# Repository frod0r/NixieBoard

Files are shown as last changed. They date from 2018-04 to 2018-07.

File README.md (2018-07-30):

Here I try to recreate the schematics and layout of the nixie clock from this nice instrucables creator:
http://www.instructables.com/id/simple-user-adjustable-DIY-Nixie-Clock/

Please note that I am done BUT I built the clock and it does not work. I have not figured out if it is the components or my plans. I will try to debug it and update here as soon as it works

The reason for me doing so is so that I can generate gerber files with wich I or you can easily order the pcb istead of echtching it oneself :)
If you Andrea Biffi (The creator of the original plans on wich I base my on) want me to remove this respority for a reason, please contact me and I 
will do so.

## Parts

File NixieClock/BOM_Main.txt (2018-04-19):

Partlist

Exported from MainClock.brd at 19.04.18 18:20

EAGLE Version 8.7.1 Copyright (c) 1988-2018 Autodesk, Inc.

Assembly variant: 

Part        Value          Package      Library             Position (mm)         Orientation

+180V(TEST)                1X01         pinhead             (6 12)                R0
9V/12-35V                  SPC4078      con-jack            (155.65 8.31)         R90
12-35V/9V                  255SB        switch              (168 30)              R90
ANODE                      1X06         pinhead             (6 28)                R270
BUZZER      F/TMB          F/TMB        buzzer              (158 44)              R180
C1          1uF 350v       E5-10,5      resistor            (70.21 15.94)         R0
C2          470uF 25v      E5-10,5      resistor            (114 32)              R0
C3          2n2            C025-024X044 resistor            (106 40.5)            R90
C4          47pF           C025-024X044 resistor            (82 32)               R90
C5          22pF           C025-025X050 resistor            (136 28)              R270
C6          22pF           C025-025X050 resistor            (142 28)              R90
C7          10uF 16V       E5-6         resistor            (148 30)              R270
C8          100uF 50V      E5-8,5       resistor            (138 20)              R180
C9          100uF          E5-8,5       resistor            (148 38)              R180
C10         10uF 25V       E5-6         resistor            (148 22)              R180
CATHODDETOX                B3F-31XX     switch-omron        (149 51)              R180
CATHODE                    1X10         pinhead             (78 17.5)             R90
D1          BYT01          F126-10      diode               (88 36)               R0
D2          1N914          DO35-10      diode               (102 10)              R0
D3          1N4004         DO41-10      diode               (156 16)              R180
D4          1N4004         DO41-10      diode               (158 34)              R180
GND                        1X01         pinhead             (56 50.5)             R0
HOUR                       B3F-31XX     switch-omron        (168 18)              R90
IC1         MEGA8-P        DIL28-3      atmel               (126.47 22.83)        R90
IC2         74141N         DIL16        74xx-us             (88 15.5)             R90
IC3         NE555          DIL-08       st-microelectronics (114 44)              R180
L1          100uH 1A       MESC26       inductors           (100 36)              R90
L7805CV                    78XXS        v-reg               (158 26)              R180
L7809                      78XXS        v-reg               (158 18)              R180
MIN                        B3F-31XX     switch-omron        (168 8)               R90
NEON                       1X02         pinhead             (78 33)               R270
OFF/ON                     255SB        switch              (168 42)              R90
POWER_LED                  LED5MM       led                 (125.5 48)            R270
Q1          MPSA 42        TO92         transistor          (46 46)               R270
Q2          MPSA 42        TO92         transistor          (46 40)               R270
Q3          MPSA 42        TO92         transistor          (46 32)               R270
Q4          MPSA 42        TO92         transistor          (46 24)               R270
Q5          MPSA 92        TO92-EBC     transistor          (26 16)               R90
Q6          MPSA 92        TO92-EBC     transistor          (26 48)               R90
Q7          MPSA 92        TO92-EBC     transistor          (26 40)               R90
Q8          MPSA 92        TO92-EBC     transistor          (26 32)               R90
Q9          MPSA 92        TO92-EBC     transistor          (26 24)               R90
Q10         IRF740         TO220BV      transistor-power    (102 20)              R0
Q11         BC547          TO92         transistor          (93.89 47.14)         R90
Q12         MPSA 92        TO92-EBC     transistor          (26 8)                R90
Q13         MPSA 42        TO92         transistor          (46 16)               R270
Q14         MPSA 42        TO92         transistor          (46 8)                R270
Q15         MPSA55         TO92-BCE     transistor          (102 6)               R180
QUARTZ      16.000MHz      HC49/S       crystal             (138 36)              R0
R1          33k            0309/10      resistor            (56 46)               R180
R2          33k            0309/10      resistor            (56 40)               R180
R3          33k            0309/10      resistor            (56 32)               R180
R4          33k            0309/10      resistor            (56 24)               R180
R5          33k            0309/10      resistor            (114 18)              R0
R6          100k           0309/10      resistor            (16 46)               R180
R7          100k           0309/10      resistor            (16 38)               R180
R8          100k           0309/10      resistor            (16 30)               R180
R9          100k           0309/10      resistor            (16 22)               R180
R10         470k           0309/10      resistor            (38 48)               R180
R11         470k           0309/10      resistor            (38 40)               R180
R12         470k           0309/10      resistor            (38 32)               R180
R13         470k           0309/10      resistor            (38 24)               R180
R14         1k             0309/10      resistor            (114 24)              R0
R15         1k             0309/10      resistor            (90 31)               R0
R16         10k            0309/10      resistor            (106 32)              R270
R17         220k           0309/10      resistor            (88 42)               R180
R18         407R           0309/10      resistor            (80.02 45.55)         R90
R19         1k             RTRIM3339P   resistor            (86 48)               R90
R20         15k            0309/10      resistor            (16 50)               R0
R21         15k            0309/10      resistor            (16 42)               R0
R22         15k            0309/10      resistor            (16 34)               R0
R23         15k            0309/10      resistor            (16 18)               R0
R24         15k            0309/10      resistor            (16 26)               R0
R25         1k             0309/10      resistor            (114 12)              R180
R26         15k            0309/10      resistor            (16 10)               R0
R27         220            0309/10      resistor            (138 48)              R180
R28         100k           0309/10      resistor            (16 14)               R180
R29         470k           0309/10      resistor            (38 16)               R180
R30         100k           0309/10      resistor            (16 6)                R180
R31         470k           0309/10      resistor            (38 8)                R180
R32         33k            0309/10      resistor            (56 16)               R180
R33         33k            0309/10      resistor            (56 8)                R180
R34         100 Ohm        0411/15      resistor            (138 44)              R0
R35         1k             0309/10      resistor            (136 10)              R270
R36         220k           0309/10      resistor            (74 38)               R180
R37         220k           0309/10      resistor            (72 28)               R270
RESET                      B3F-10XX     switch-omron        (144 8)               R0
RTC                        1X04         pinhead             (114 6)               R0

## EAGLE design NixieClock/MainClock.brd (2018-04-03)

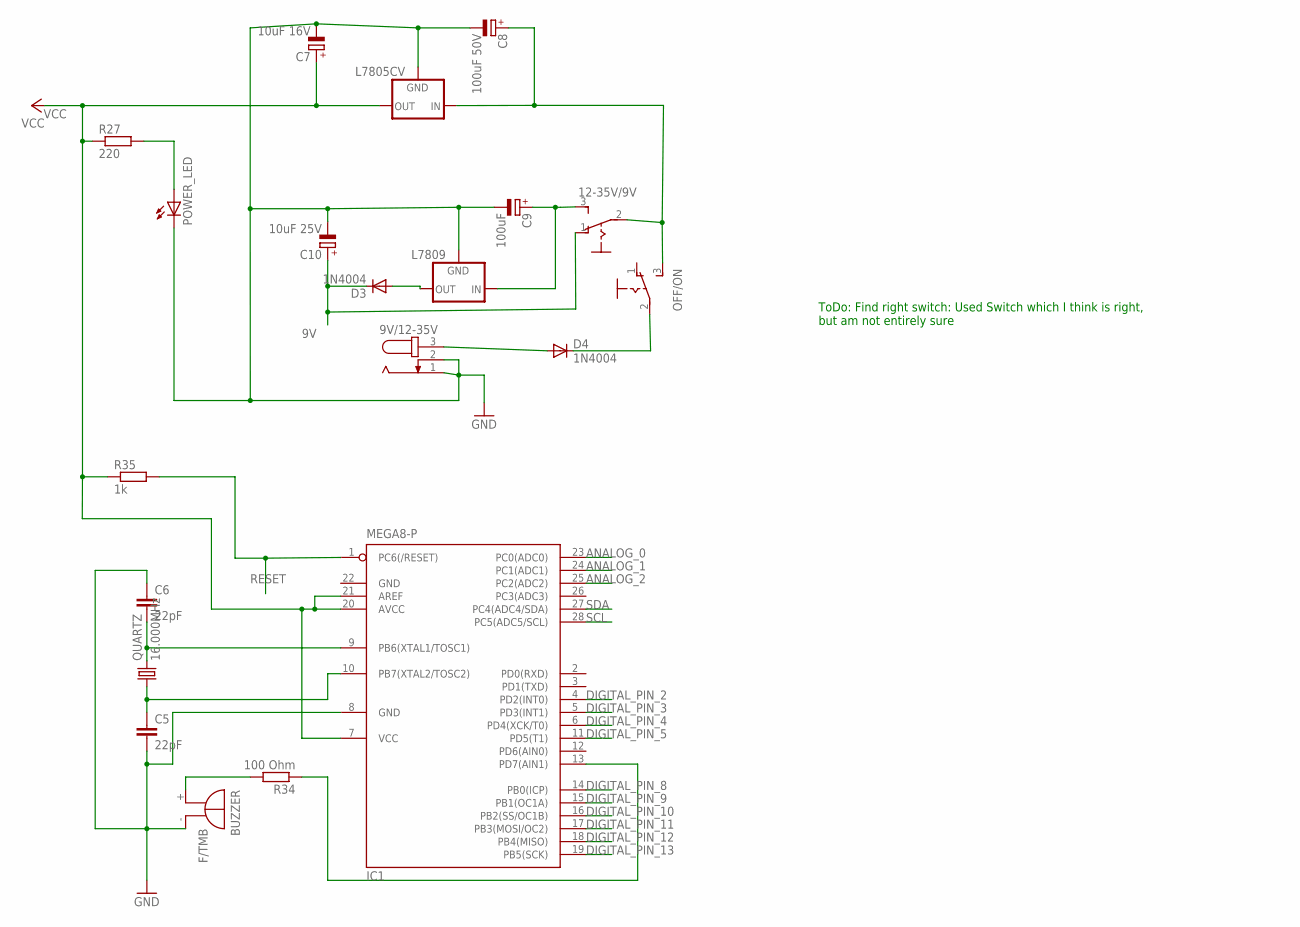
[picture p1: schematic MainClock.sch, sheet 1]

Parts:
9V/12-35V: JACK-PLUG1; SPC4078
12-35V/9V: 255SB
BUZZER: F/TMB
C5, C6: 22pF; C025-025X050
C7: 10uF 16V; E5-6
C8: 100uF 50V; E5-8,5
C9: 100uF; E5-8,5
C10: 10uF 25V; E5-6
D3, D4: 1N4004; DO41-10
IC1: MEGA8-P; DIL28-3
L7805CV, L7809: 78XXS
OFF/ON: 255SB
POWER_LED: LED5MM
QUARTZ: 16.000MHz; HC49/S
R27: 220; 0309/10
R34: 100 Ohm; 0411/15
R35: 1k; 0309/10

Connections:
9V: 12-35V/9V.1 (O), C10.+, D3.C; also elsewhere on the board
ANALOG_0: IC1.23 (PC0(ADC0)); also elsewhere on the board
ANALOG_1: IC1.24 (PC1(ADC1)); also elsewhere on the board
ANALOG_2: IC1.25 (PC2(ADC2)); also elsewhere on the board
DIGITAL_PIN_2: IC1.4 (PD2(INT0)); also elsewhere on the board
DIGITAL_PIN_3: IC1.5 (PD3(INT1)); also elsewhere on the board
DIGITAL_PIN_4: IC1.6 (PD4(XCK/T0)); also elsewhere on the board
DIGITAL_PIN_5: IC1.11 (PD5(T1)); also elsewhere on the board
DIGITAL_PIN_8: IC1.14 (PB0(ICP)); also elsewhere on the board
DIGITAL_PIN_9: IC1.15 (PB1(OC1A)); also elsewhere on the board
DIGITAL_PIN_10: IC1.16 (PB2(SS/OC1B)); also elsewhere on the board
DIGITAL_PIN_11: IC1.17 (PB3(MOSI/OC2)); also elsewhere on the board
DIGITAL_PIN_12: IC1.18 (PB4(MISO)); also elsewhere on the board
DIGITAL_PIN_13: IC1.19 (PB5(SCK)); also elsewhere on the board
GND: 9V/12-35V.1, 9V/12-35V.2, BUZZER.-, C5.2, C6.1, C7.-, C8.-, C9.-, C10.-, IC1.8 (GND), IC1.22 (GND), L7805CV.GND, L7809.GND, POWER_LED.K (C); also elsewhere on the board
unnamed: C6.2, IC1.9 (PB6(XTAL1/TOSC1)), QUARTZ.2
unnamed: C5.1, IC1.10 (PB7(XTAL2/TOSC2)), QUARTZ.1
unnamed: BUZZER.+, R34.2
unnamed: IC1.13 (PD7(AIN1)), R34.1
unnamed: 9V/12-35V.3, D4.A
unnamed: D4.C, OFF/ON.2
unnamed: 12-35V/9V.2, C8.+, L7805CV.IN, OFF/ON.3 (S)
unnamed: 12-35V/9V.3 (S), C9.+, L7809.IN
unnamed: POWER_LED.A, R27.2
unnamed: D3.A, L7809.OUT
RESET: IC1.1 (PC6(/RESET)), R35.2; also elsewhere on the board
SCL: IC1.28 (PC5(ADC5/SCL)); also elsewhere on the board
SDA: IC1.27 (PC4(ADC4/SDA)); also elsewhere on the board
VCC: C7.+, IC1.7 (VCC), IC1.20 (AVCC), IC1.21 (AREF), L7805CV.OUT, R27.1, R35.1; also elsewhere on the board

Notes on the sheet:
ToDo: Find right switch: Used Switch which I think is right, but am not entirely sure

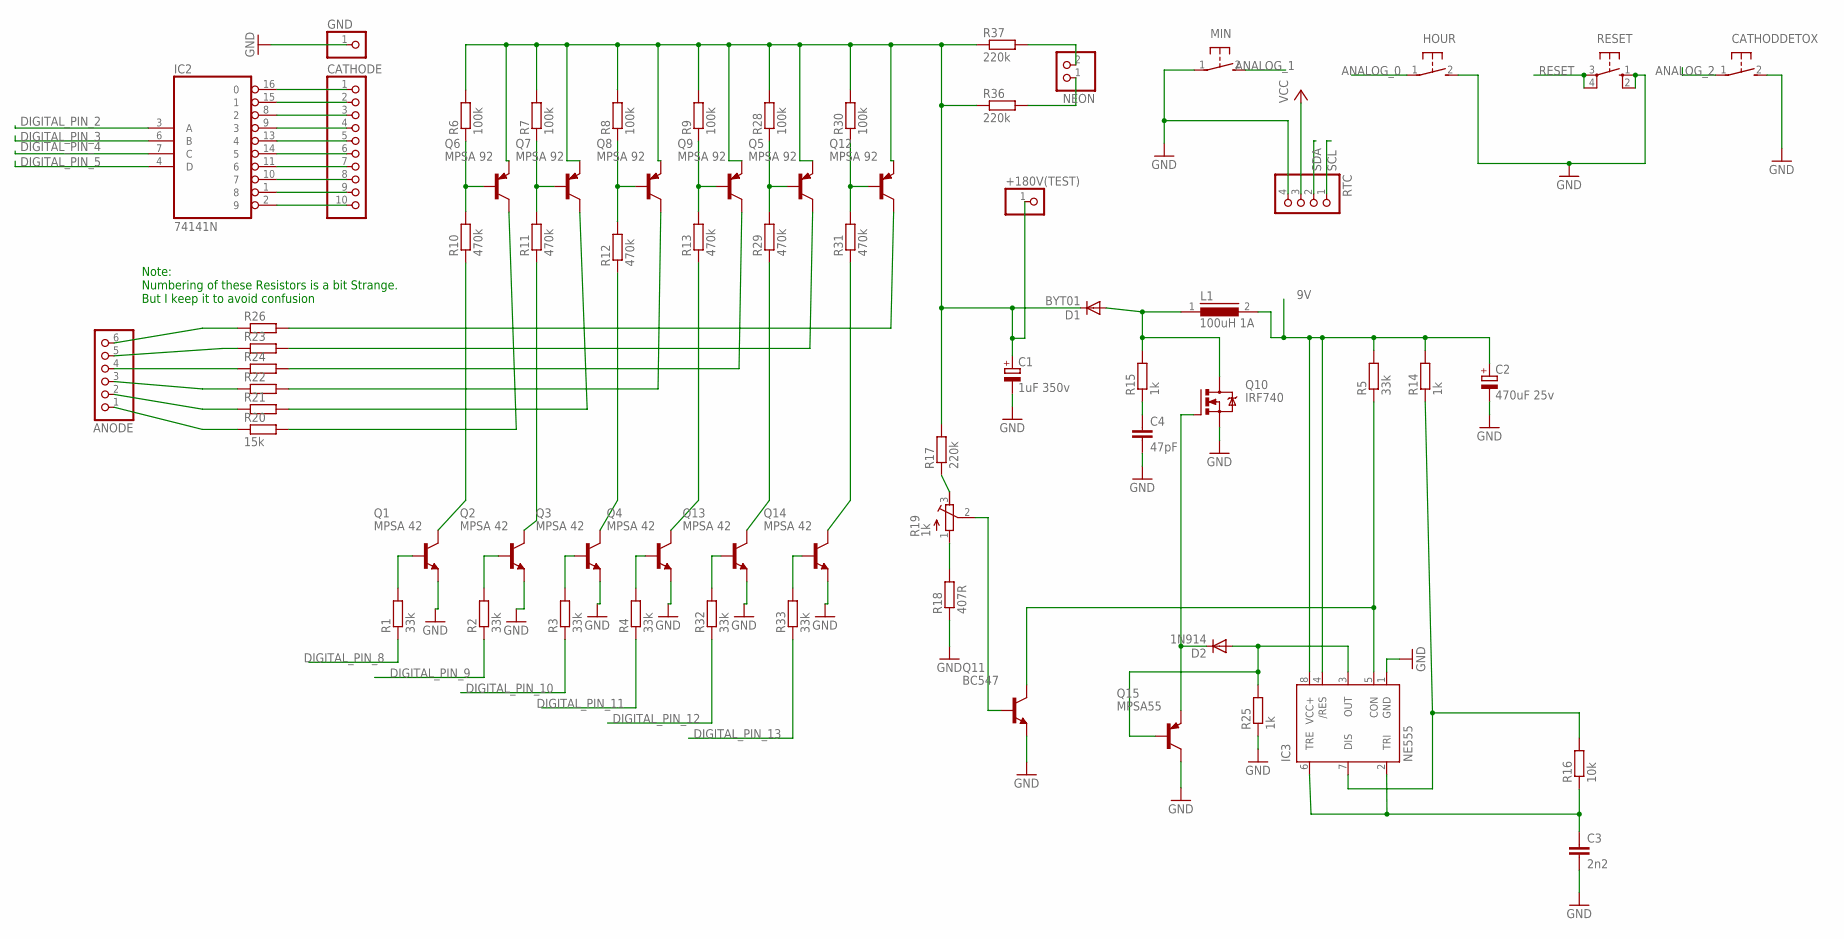
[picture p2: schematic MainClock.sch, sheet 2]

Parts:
+180V(TEST): PINHD-1X1; 1X01
ANODE: PINHD-1X6; 1X06
C1: 1uF 350v; E5-10,5
C2: 470uF 25v; E5-10,5
C3: 2n2; C025-024X044
C4: 47pF; C025-024X044
CATHODDETOX: 31-XX; B3F-31XX
CATHODE: PINHD-1X10; 1X10
D1: BYT01; F126-10
D2: 1N914; DO35-10
GND: PINHD-1X1; 1X01
HOUR: 31-XX; B3F-31XX
IC2: 74141N; DIL16
IC3: NE555; DIL-08
L1: 100uH 1A; MESC26
MIN: 31-XX; B3F-31XX
NEON: PINHD-1X2; 1X02
Q1, Q2, Q3, Q4, Q13, Q14: MPSA 42; TO92
Q5, Q6, Q7, Q8, Q9, Q12: MPSA 92; TO92-EBC
Q10: IRF740; TO220BV
Q11: BC547; TO92
Q15: MPSA55; TO92-BCE
R1, R2, R3, R4, R5, R32, R33: 33k; 0309/10
R6, R7, R8, R9, R28, R30: 100k; 0309/10
R10, R11, R12, R13, R29, R31: 470k; 0309/10
R14, R15, R25: 1k; 0309/10
R16: 10k; 0309/10
R17, R36, R37: 220k; 0309/10
R18: 407R; 0309/10
R19: 1k; RTRIM3339P
R20, R21, R22, R23, R24, R26: 15k; 0309/10
RESET: 10-XX; B3F-10XX
RTC: PINHD-1X4; 1X04

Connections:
9V: C2.+, IC3.4 (/RES), IC3.8 (VCC+), L1.2, R5.2, R14.2; also elsewhere on the board
ANALOG_0: HOUR.1; also elsewhere on the board
ANALOG_1: MIN.2 (S); also elsewhere on the board
ANALOG_2: CATHODDETOX.1; also elsewhere on the board
DIGITAL_PIN_2: IC2.3 (A); also elsewhere on the board
DIGITAL_PIN_3: IC2.6 (B); also elsewhere on the board
DIGITAL_PIN_4: IC2.7 (C); also elsewhere on the board
DIGITAL_PIN_5: IC2.4 (D); also elsewhere on the board
DIGITAL_PIN_8: R1.1; also elsewhere on the board
DIGITAL_PIN_9: R2.1; also elsewhere on the board
DIGITAL_PIN_10: R3.1; also elsewhere on the board
DIGITAL_PIN_11: R4.1; also elsewhere on the board
DIGITAL_PIN_12: R32.1; also elsewhere on the board
DIGITAL_PIN_13: R33.1; also elsewhere on the board
GND: C1.-, C2.-, C3.2, C4.2, CATHODDETOX.2 (S), GND.1, HOUR.2 (S), IC2.12 (GND), IC3.1 (GND), MIN.1, Q1.1 (E), Q2.1 (E), Q3.1 (E), Q4.1 (E), Q10.S, Q11.1 (E), Q13.1 (E), Q14.1 (E), Q15.C, R18.1, R25.1, RESET.1 (S), RESET.2 (S1), RTC.4; also elsewhere on the board
unnamed: ANODE.6, R26.1
unnamed: ANODE.5, R23.1
unnamed: ANODE.4, R24.1
unnamed: ANODE.3, R22.1
unnamed: ANODE.2, R21.1
unnamed: ANODE.1, R20.1
unnamed: Q1.2 (B), R1.2
unnamed: Q2.2 (B), R2.2
unnamed: Q13.2 (B), R32.2
unnamed: Q14.2 (B), R33.2
unnamed: Q4.2 (B), R4.2
unnamed: Q3.2 (B), R3.2
unnamed: Q1.3 (C), R10.1
unnamed: Q2.3 (C), R11.1
unnamed: Q3.3 (C), R12.1
unnamed: Q4.3 (C), R13.1
unnamed: Q13.3 (C), R29.1
unnamed: Q14.3 (C), R31.1
unnamed: Q12.B, R30.1, R31.2
unnamed: Q5.B, R28.1, R29.2
unnamed: Q9.B, R9.1, R13.2
unnamed: Q8.B, R8.1, R12.2
unnamed: Q7.B, R7.1, R11.2
unnamed: +180V(TEST).1, C1.+, D1.C, Q5.E, Q6.E, Q7.E, Q8.E, Q9.E, Q12.E, R6.2, R7.2, R8.2, R9.2, R17.2, R28.2, R30.2, R36.1, R37.1
unnamed: Q12.C, R26.2
unnamed: Q5.C, R23.2
unnamed: Q9.C, R24.2
unnamed: Q8.C, R22.2
unnamed: Q7.C, R21.2
unnamed: Q6.C, R20.2
unnamed: CATHODE.1, IC2.16 (0)
unnamed: CATHODE.2, IC2.15 (1)
unnamed: CATHODE.6, IC2.14 (5)
unnamed: CATHODE.5, IC2.13 (4)
unnamed: CATHODE.7, IC2.11 (6)
unnamed: CATHODE.8, IC2.10 (7)
unnamed: CATHODE.4, IC2.9 (3)
unnamed: CATHODE.3, IC2.8 (2)
unnamed: CATHODE.9, IC2.1 (8)
unnamed: CATHODE.10, IC2.2 (9)
unnamed: NEON.1, R36.2
unnamed: NEON.2, R37.2
unnamed: C3.1, IC3.2 (TRI), IC3.6 (TRE), R16.1
unnamed: Q6.B, R6.1, R10.2
unnamed: D1.A, L1.1, Q10.D, R15.2
unnamed: C4.1, R15.1
unnamed: IC3.7 (DIS), R14.1, R16.2
unnamed: IC3.5 (CON), Q11.3 (C), R5.1
unnamed: R18.2, R19.1 (A)
unnamed: R17.1, R19.3 (E)
unnamed: D2.A, IC3.3 (OUT), Q15.B, R25.2
unnamed: D2.C, Q10.G, Q15.E
unnamed: Q11.2 (B), R19.2 (S)
RESET: RESET.3, RESET.4 (P1); also elsewhere on the board
SCL: RTC.1; also elsewhere on the board
SDA: RTC.2; also elsewhere on the board
VCC: IC2.5 (VCC), RTC.3; also elsewhere on the board

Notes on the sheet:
Note: Numbering of these Resistors is a bit Strange. But I keep it to avoid confusion

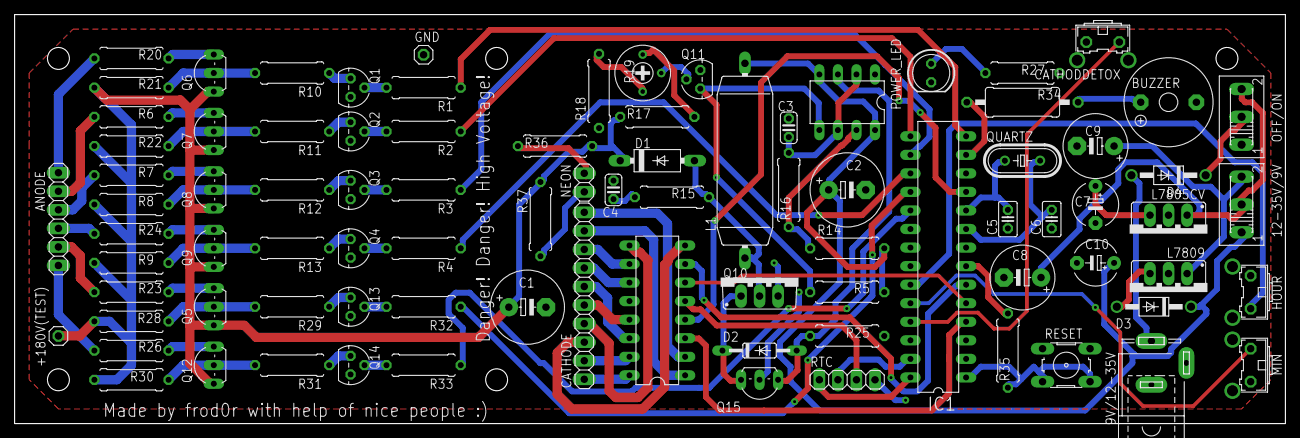
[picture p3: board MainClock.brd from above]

Board: 2 copper layers, 174.0 x 56.0 mm, 88 parts (0 on the bottom side), 82 nets.

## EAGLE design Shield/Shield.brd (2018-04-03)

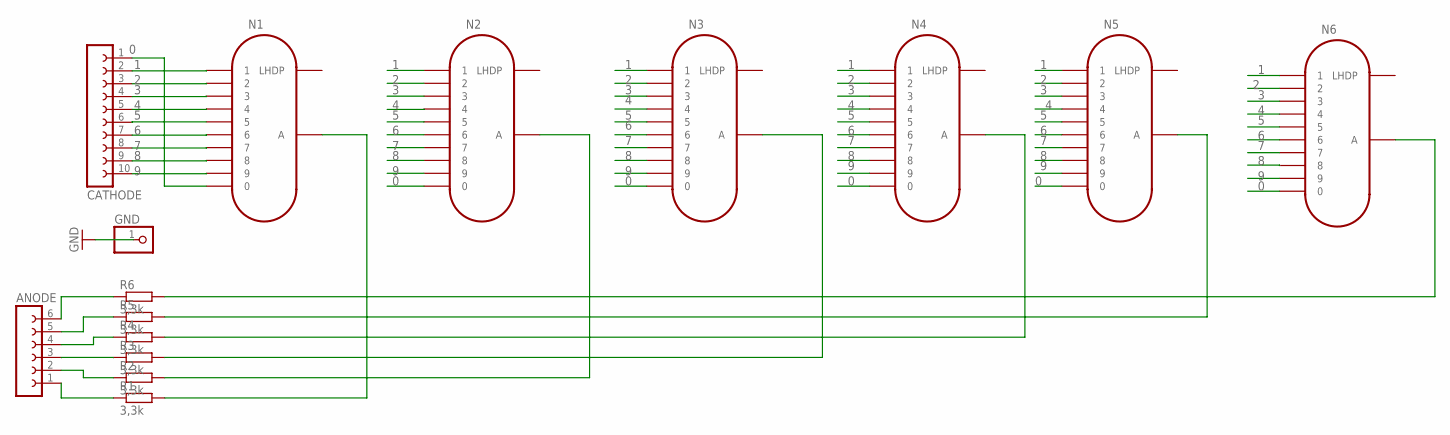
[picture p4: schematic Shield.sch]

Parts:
ANODE: FE06-1; FE06
CATHODE: FE10-1; FE10
GND: PINHD-1X1; 1X01
N1, N2, N3, N4, N5, N6: IN-12B; IN-12
R1, R2, R3, R4, R5, R6: 3,3k; 0309/12

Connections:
0: CATHODE.1, N1.0, N2.0, N3.0, N4.0, N5.0, N6.0
1: CATHODE.2, N1.1, N2.1, N3.1, N4.1, N5.1, N6.1
2: CATHODE.3, N1.2, N2.2, N3.2, N4.2, N5.2, N6.2
3: CATHODE.4, N1.3, N2.3, N3.3, N4.3, N5.3, N6.3
4: CATHODE.5, N1.4, N2.4, N3.4, N4.4, N5.4, N6.4
5: CATHODE.6, N1.5, N2.5, N3.5, N4.5, N5.5, N6.5
6: CATHODE.7, N1.6, N2.6, N3.6, N4.6, N5.6, N6.6
7: CATHODE.8, N1.7, N2.7, N3.7, N4.7, N5.7, N6.7
8: CATHODE.9, N1.8, N2.8, N3.8, N4.8, N5.8, N6.8
9: CATHODE.10, N1.9, N2.9, N3.9, N4.9, N5.9, N6.9
GND: GND.1
unnamed: ANODE.1, R1.1
unnamed: ANODE.6, R6.1
unnamed: ANODE.5, R5.1
unnamed: ANODE.2, R2.1
unnamed: ANODE.3, R3.1
unnamed: ANODE.4, R4.1
unnamed: N1.A, R1.2
unnamed: N3.A, R3.2
unnamed: N4.A, R4.2
unnamed: N5.A, R5.2
unnamed: N6.A, R6.2
unnamed: N2.A, R2.2

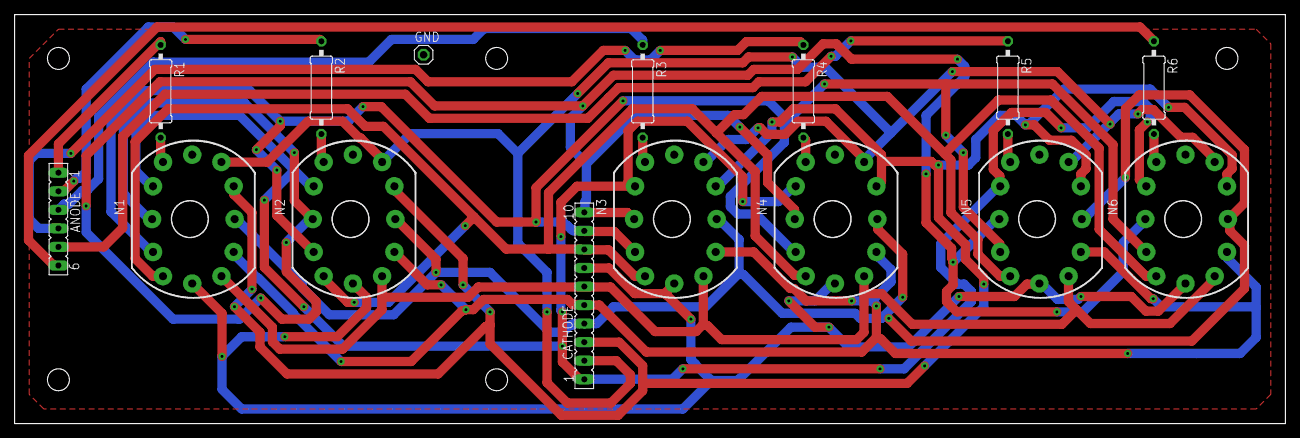
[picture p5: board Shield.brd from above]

Board: 2 copper layers, 174.0 x 56.0 mm, 15 parts (0 on the bottom side), 22 nets.

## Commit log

2018-03-12 init commit
    [MainClock.sch]
2018-03-22 Finished first sheet. Declares the 5V as VCC and began second sheet.
    [MainClock.sch]
2018-03-22 Completed Section A of Sheet 2
    [MainClock.sch]
2018-03-23 Completed Section B of Sheet 2 and exchanged female heades with pins.
    [MainClock.sch]
2018-03-31 Finished 2nd Sheet. Still have a few ToDos though
    [MainClock.sch]
2018-03-31 Resolved ToDOs
    [MainClock.sch]
2018-03-31 Placed half of the components
    [MainClock.brd, MainClock.sch]
2018-03-31 Placed all Parts
    [MainClock.brd]
2018-03-31 Began Routing
    [MainClock.brd]
2018-03-31 Routed the rest w the help of autorouter
    [MainClock.brd, MainClock.sch]
2018-04-01 Added Holes
    [MainClock.brd, MainClock.sch]
2018-04-01 Moved Names and Values so that they are easily readable
    [MainClock.brd, MainClock.sch]
2018-04-02 Added a button to the board and added the shield
    [MainClock.brd, MainClock.sch, Shield.brd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]
2018-04-02 spaced routes out
    [Shield.brd, Shield.sch]
2018-04-03 forgot to save before commit... Comment: See last commit
    [Shield.brd, Shield.sch]
2018-04-03 applied rules to shield
    [Shield.brd]
2018-04-03 applied rules to main
    [MainClock.brd]
2018-04-19 Added BOM and gitignore files
2018-04-24 Fixed Mistake Some Resistor Labels were swapped. (The Values were at the Right Place)
